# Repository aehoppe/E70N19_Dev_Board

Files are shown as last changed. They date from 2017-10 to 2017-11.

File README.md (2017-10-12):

# E70N19_Dev_Board
 Repository for developing an ATSAME70N19-based dev board for Eclectronics FA 2017

## Brief Description of Board Design

Currently the board is designed to fit onto a 10cm X 10cm PCB. We will be using female header pins, much like an Arduino, on opposite edges of the PCB. 

## Changes to Schematic & BOM

There were no changes to the BOM.

The schematic had a few modifications based on feedback we received.

- Adding a voltage divider to TPS2112A to prevent brown out
- Added load capacitors to our RTC crystal
- Added a 10uF to BM71
- Added power LED to show status of power
- Changed nRST button to drive it to ground instead of power
- Added 30Ohm resistors to USB data lines
- Added connections to ground, 3v3 and VBUS to connectors

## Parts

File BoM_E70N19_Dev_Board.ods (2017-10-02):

Reference | Value | Datasheet | Tolerance | Digikey | Price | In Stock
C1 | 4.7uF | https://www.digikey.com/product-detail/en/samsung-electro-mechanics-america-inc/CL10B475KQ8NQNC/1276-2087-1-ND/3890172 |  | 1276-2087-1-ND | $0.10 | No
C3 | 4.7uF |  |  |  | $0.10 | No
C6 | 4.7uF |  |  |  | $0.10 | No
C23 | 18pF | https://www.digikey.com/product-detail/en/murata-electronics-north-america/GRM1555C1H180JA01D/490-5858-1-ND/2854384 |  | 490-5858-1-ND | $0.10 | No
C24 | 18pF |  |  |  | $0.10 | No
C10 | 100nF |  |  |  |  | Yes
C11 | 100nF |  |  |  |  | Yes
C12 | 100nF |  |  |  |  | Yes
C13 | 100nF |  |  |  |  | Yes
C14 | 1uF |  |  |  |  | Yes
C15 | 100nF |  |  |  |  | Yes
C16 | 100nF |  |  |  |  | Yes
C17 | 100nF |  |  |  |  | Yes
C18 | 100nF |  |  |  |  | Yes
C19 | 100nF |  |  |  |  | Yes
C2 | 10uF |  |  |  |  | Yes
C20 | 100nF |  |  |  |  | Yes
C21 | 100nF |  |  |  |  | Yes
C22 | 10pF |  |  |  |  | Yes
C25 | 1uF |  |  |  |  | Yes
C26 | 100nF |  |  |  |  | Yes
C27 | 100nF |  |  |  |  | Yes
C28 | 100nF |  |  |  |  | Yes
C4 | 0.1uF |  |  |  |  | Yes
C5 | 10uF |  |  |  |  | Yes
C7 | 100nF |  |  |  |  | Yes
C8 | 100nF |  |  |  |  | Yes
C9 | 100nF |  |  |  |  | Yes
R1 | 475 |  |  |  |  | Yes
R10 | 100K |  |  |  |  | Yes
R11 | 100K |  |  |  |  | Yes
R2 | 402 |  |  |  |  | Yes
R3 | 2K |  |  |  |  | Yes
R4 | 4.99K |  |  |  |  | Yes
R12 | 63.4 |  |  |  |  | Yes
R5 | 4.75K |  |  |  |  | Yes
R6 | 0 | https://www.digikey.com/product-detail/en/yageo/RC0603JR-070RL/311-0.0GRCT-ND/729622 |  | 311-0.0GRCT-ND | $0.10 | No
R7 | -1 (0 but DNP) |  |  |  |  | No
R8 | 402 |  |  |  |  | Yes
R9 | 100K |  |  |  |  | Yes
D1 | LED |  |  |  |  | Yes
D2 | LED |  |  |  |  | Yes
FP1 | BM71BLES1FC2 | https://www.digikey.com/product-detail/en/microchip-technology/BM71BLES1FC2-0002AA/BM71BLES1FC2-0002AA-ND/5886086 | N/A | BM71BLES1FC2-0002AA-ND | $7.38 | No
J1 | USB_OTG |  |  |  |  | Yes
J2 | Battery | https://www.digikey.com/product-detail/en/jst-sales-america-inc/S2B-PH-SM4-TB-LF-SN/455-1749-1-ND/926846 |  | 455-1749-1-ND | $0.58 | No
J3 | JTAGSEL_JUMPER 1x3 |  |  |  |  | Yes
J5 | ERASE_JUMPER 1x3 |  |  |  |  | Yes
J4 | UART_PROG 1x2 |  |  |  |  | Yes
J7 | CAN 1x2 |  |  |  |  | Yes
J6 | ARM-Cortex-Debug-10 | https://www.digikey.com/product-detail/en/samtec-inc/FTSH-105-01-F-DV-K/SAM8796-ND/2649974 |  | SAM8796-ND | $2.90 | No
J8 | Conn_02x15_Counter_Clockwise | https://www.digikey.com/product-detail/en/sullins-connector-solutions/PPTC152LFBN-RC/S7083-ND/810221 |  | S7083-ND | $2.74 | No
J9 | Conn_02x15_Counter_Clockwise |  |  |  | $2.74 | No
L1 | 470R @ 100MHz |  |  | 445-5218-1-ND | $0.10 | No
L2 | 470R @ 100MHz |  |  |  | $0.10 | No
SW1 | NRST_BUTTON |  |  |  |  | Yes
U1 | MCP73831 | http://ww1.microchip.com/downloads/en/DeviceDoc/20001984g.pdf |  | MCP73831T-2ACI/OTCT-ND | $0.59 | No
U2 | TPS2112A | http://www.ti.com/lit/ds/symlink/tps2112a.pdf |  | 296-16938-1-ND | $2.46 | No
U3 | SPX3819M5-L-3-3 | https://www.digikey.com/product-detail/en/exar-corporation/SPX3819M5-L-3-3-TR/1016-1873-1-ND/3586590 |  | 1016-1873-1-ND | $0.72 | No
U4 | ATSAME70N19 |  |  | ATSAME70N19A-AN-ND | $9.38 | No
U5 | RT9818A-18GV |  |  | RT9818A-18GV-ND | $0.40 | No | <- Out of stock, Substitute: 1028-1020-1-ND
U6 | SN65HVD233-Q1 | https://www.digikey.com/product-detail/en/texas-instruments/SN65HVD233DR/296-35967-1-ND/4134960 |  | 296-35967-1-ND | $2.75 | No
Y1 | Crystal_GND23_Small | https://www.digikey.com/products/en?keywords=%20535-10240-1-ND%20 |  | 535-10240-1-ND | $0.40 | No
Y2 | Crystal | https://support.epson.biz/td/api/doc_check.php?dl=brief_FA-238V_en.pdf |  | SER3686CT-ND | $0.43 | No
 | Jumper 1x2 | https://www.digikey.com/product-detail/en/sullins-connector-solutions/SPC02SYAN/S9001-ND/76375 |  | S9001-ND | $0.13 | No
 | Jumper 1x2 |  |  |  | $0.13 | No
 |  |  |  |  | $34.40

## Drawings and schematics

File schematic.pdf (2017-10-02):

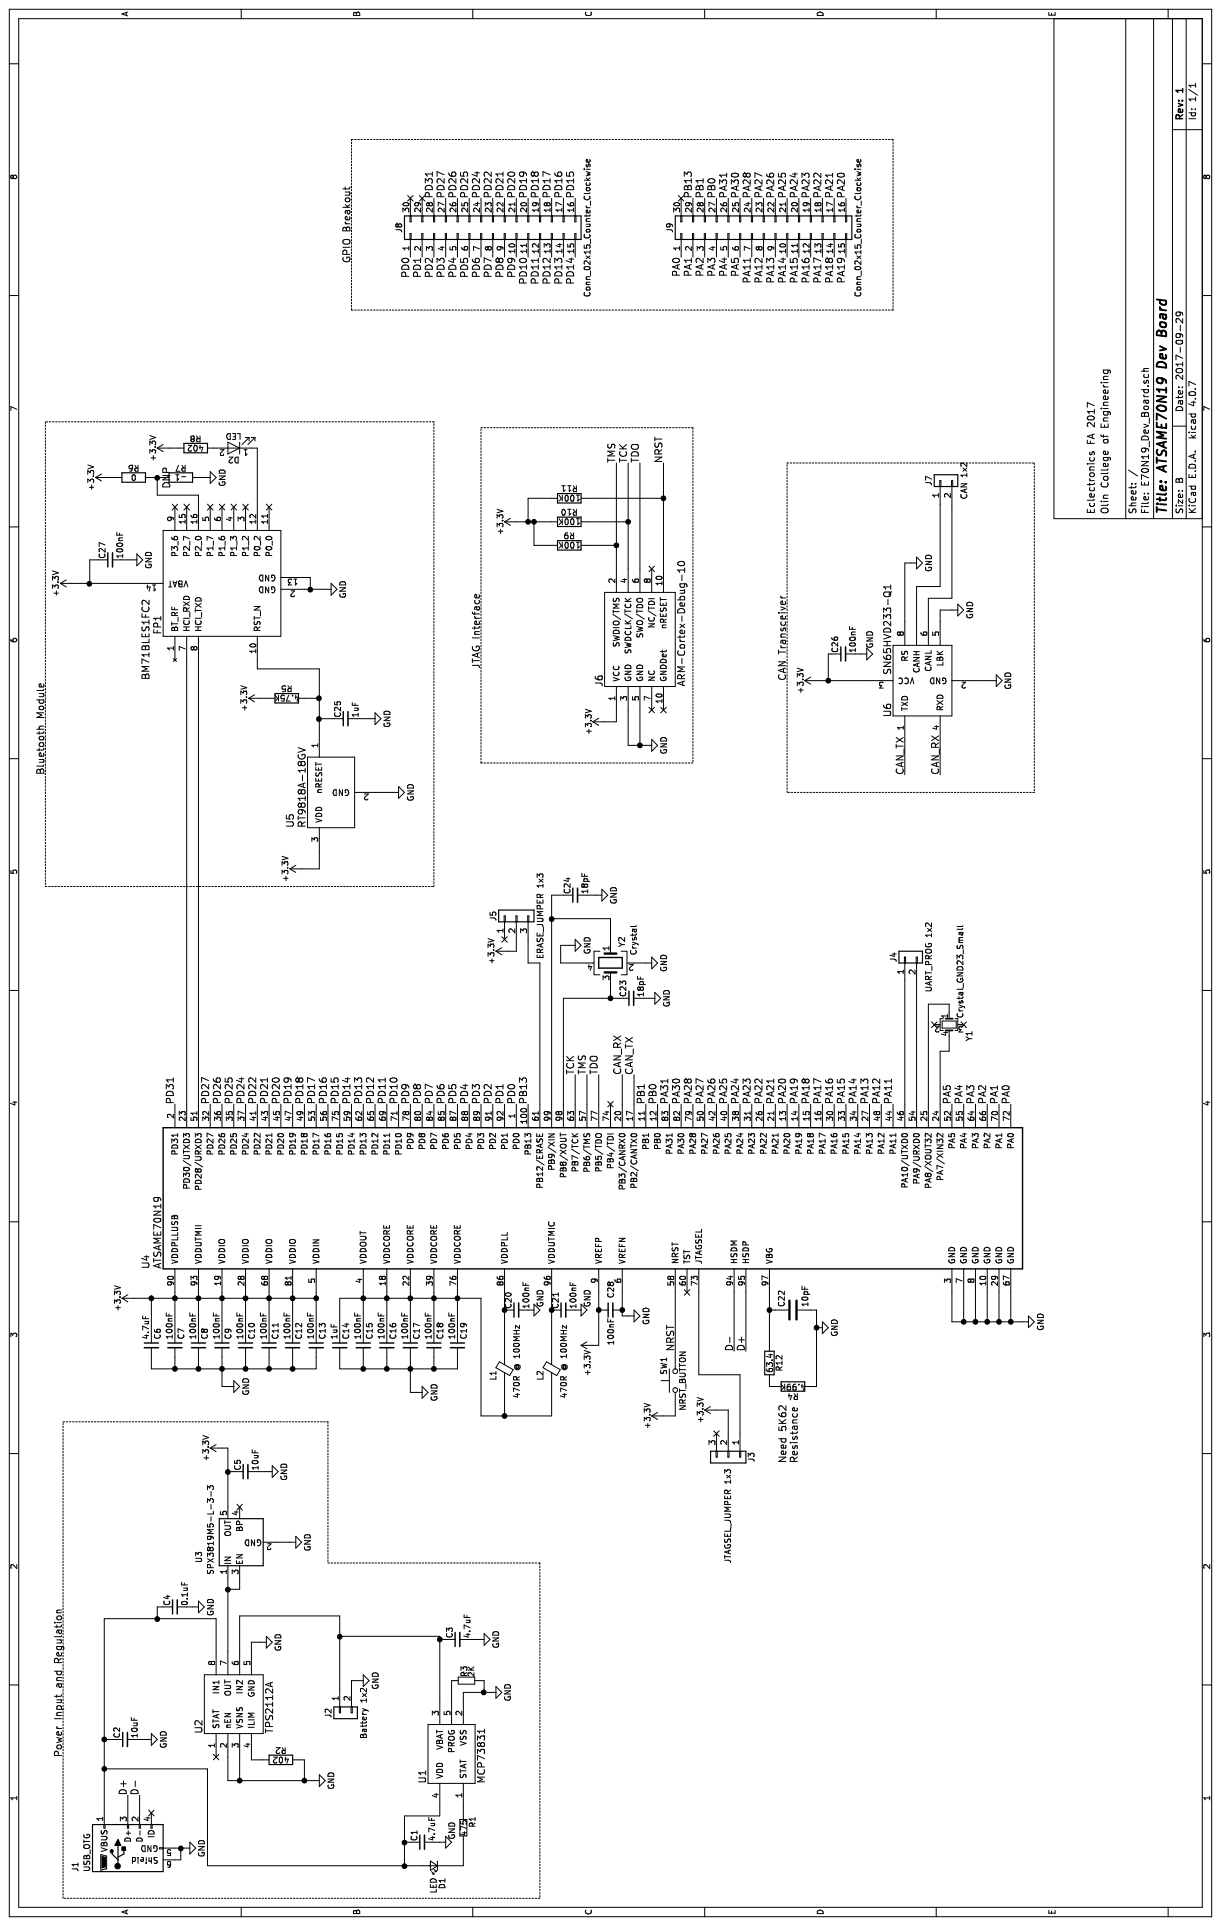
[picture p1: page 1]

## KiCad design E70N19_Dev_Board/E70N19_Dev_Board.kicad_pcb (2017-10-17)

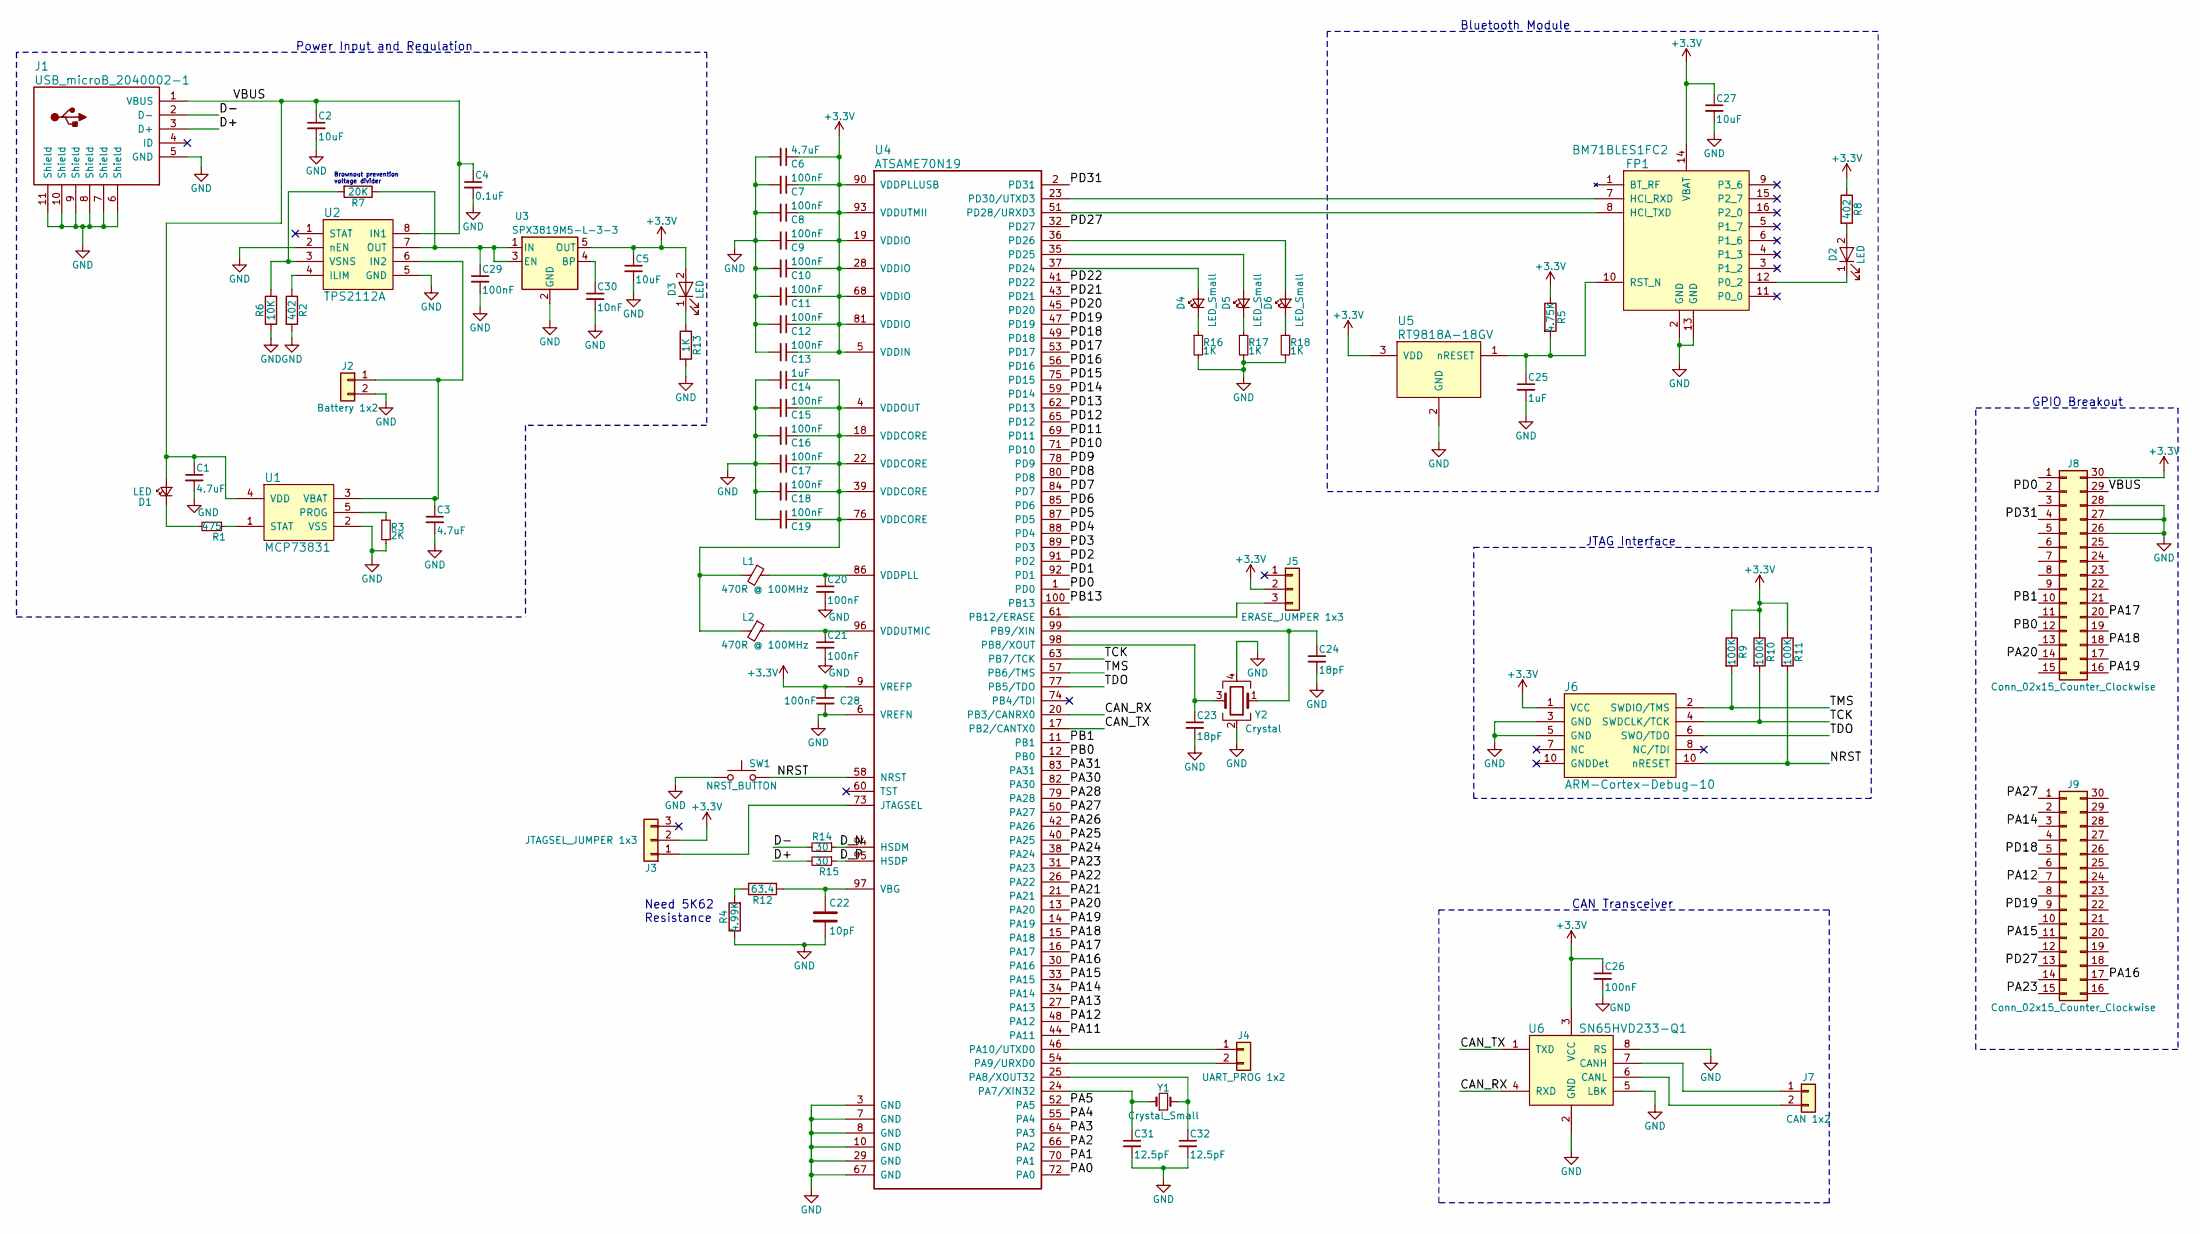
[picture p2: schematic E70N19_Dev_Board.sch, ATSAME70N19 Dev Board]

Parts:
C1, C3, C6: 4.7uF; C_0603
C2, C5, C27: 10uF; C_0805
C4: 0.1uF; C_0603
C7, C8, C9, C10, C11, C12, C13, C15, C16, C17, C18, C19, C20, C21, C26, C28, C29: 100nF; C_0603
C14, C25: 1uF; C_0603
C22: 10pF; C_0603
C23, C24: 18pF; C_0603
C30: 10nF; C_0603
C31, C32: 12.5pF; C_0603
D1, D2, D3: LED; LED_0805
D4, D5, D6: LED_Small; LED_0805
FP1: BM71BLES1FC2
J1: USB_microB_2040002-1
J2: Battery 1x2; JST_PH_S2B-PH-SM4-TB_02x2.00mm_Angled
J3: JTAGSEL_JUMPER 1x3; Pin_Header_Straight_1x03_Pitch2.54mm
J4: UART_PROG 1x2; Pin_Header_Straight_1x02_Pitch2.54mm
J5: ERASE_JUMPER 1x3; Pin_Header_Straight_1x03_Pitch2.54mm
J6: ARM-Cortex-Debug-10; Pin_Header_Straight_2x05_Pitch2.54mm
J7: CAN 1x2; Pin_Header_Straight_1x02_Pitch2.54mm
J8, J9: Conn_02x15_Counter_Clockwise; Pin_Header_Straight_2x15_Pitch2.54mm
L1, L2: 470R @ 100MHz; R_0603; Digikey 445-5218-1-ND
R1: 475; R_0603
R2, R8: 402; R_0603
R3: 2K; R_0603
R4: 4.99K; R_0603
R5: 4.75K; R_0603
R6: 10K; R_0603
R7: 20K; R_0603
R9, R10, R11: 100K; R_0603
R12: 63.4; R_0603
R13, R16, R17, R18: 1K; R_0603
R14, R15: 30; R_0603
SW1: NRST_BUTTON; PTS820_J15M_SMTR_LFS
U1: MCP73831; SOT-23-5
U2: TPS2112A; TSSOP-8_4.4x3mm_Pitch0.65mm
U3: SPX3819M5-L-3-3; SOT-23-5
U4: ATSAME70N19; LQFP-100_14x14mm_Pitch0.5mm
U5: RT9818A-18GV; SOT-23
U6: SN65HVD233-Q1; SOIC-8_3.9x4.9mm_Pitch1.27mm
Y1: Crystal_Small; ECS-.327-12.5-34B-TR
Y2: Crystal; Crystal_SMD_SeikoEpson_FA238-4pin_3.2x2.5mm

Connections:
+3V3: C5.1, C6.1, C7.1, C8.1, C9.1, C10.1, C11.1, C12.1, C13.1, C26.1, C27.1, C28.1, D3.2 (A), FP1.14 (VBAT), J3.2, J5.2, J6.1 (VCC), J8.30, R5.1, R8.1, R9.1, R10.1, R11.1, U3.5 (OUT), U4.5 (VDDIN), U4.9 (VREFP), U4.19 (VDDIO), U4.28 (VDDIO), U4.68 (VDDIO), U4.81 (VDDIO), U4.90 (VDDPLLUSB), U4.93 (VDDUTMII), U5.3 (VDD), U6.3 (VCC)
/CAN_RX: U4.20 (PB3/CANRX0), U6.4 (RXD)
/CAN_TX: U4.17 (PB2/CANTX0), U6.1 (TXD)
/D+: J1.3 (D+), R15.2
/D-: J1.2 (D-), R14.2
/D_N: R14.1, U4.94 (HSDM)
/D_P: R15.1, U4.95 (HSDP)
/NRST: J6.10 (GNDDet), R11.2, SW1.2, U4.58 (NRST)
/PA0: U4.72 (PA0)
/PA1: U4.70 (PA1)
/PA2: U4.66 (PA2)
/PA3: U4.64 (PA3)
/PA4: U4.55 (PA4)
/PA5: U4.52 (PA5)
/PA11: U4.44 (PA11)
/PA12: J9.7, U4.48 (PA12)
/PA13: U4.27 (PA13)
/PA14: J9.3, U4.34 (PA14)
/PA15: J9.11, U4.33 (PA15)
/PA16: J9.17, U4.30 (PA16)
/PA17: J8.20, U4.16 (PA17)
/PA18: J8.18, U4.15 (PA18)
/PA19: J8.16, U4.14 (PA19)
/PA20: J8.14, U4.13 (PA20)
/PA21: U4.21 (PA21)
/PA22: U4.26 (PA22)
/PA23: J9.15, U4.31 (PA23)
/PA24: U4.38 (PA24)
/PA25: U4.40 (PA25)
/PA26: U4.42 (PA26)
/PA27: J9.1, U4.50 (PA27)
/PA28: U4.79 (PA28)
/PA30: U4.82 (PA30)
/PA31: U4.83 (PA31)
/PB0: J8.12, U4.12 (PB0)
/PB1: J8.10, U4.11 (PB1)
/PB13: U4.100 (PB13)
/PD0: J8.2, U4.1 (PD0)
/PD1: U4.92 (PD1)
/PD2: U4.91 (PD2)
/PD3: U4.89 (PD3)
/PD4: U4.88 (PD4)
/PD5: U4.87 (PD5)
/PD6: U4.85 (PD6)
/PD7: U4.84 (PD7)
/PD8: U4.80 (PD8)
/PD9: U4.78 (PD9)
/PD10: U4.71 (PD10)
/PD11: U4.69 (PD11)
/PD12: U4.65 (PD12)
/PD13: U4.62 (PD13)
/PD14: U4.59 (PD14)
/PD15: U4.75 (PD15)
/PD16: U4.56 (PD16)
/PD17: U4.53 (PD17)
/PD18: J9.5, U4.49 (PD18)
/PD19: J9.9, U4.47 (PD19)
/PD20: U4.45 (PD20)
/PD21: U4.43 (PD21)
/PD22: U4.41 (PD22)
/PD27: J9.13, U4.32 (PD27)
/PD31: J8.4, U4.2 (PD31)
/TCK: J6.4 (SWDCLK/TCK), R10.2, U4.63 (PB7/TCK)
/TDO: J6.6 (SWO/TDO), U4.77 (PB5/TDO)
/TMS: J6.2 (SWDIO/TMS), R9.2, U4.57 (PB6/TMS)
/VBUS: C1.1, C2.1, C4.1, D1.2 (A), J1.1 (VBUS), J8.29, U1.4 (VDD), U2.8 (IN1)
GND: C1.2, C2.2, C3.2, C4.2, C5.2, C6.2, C7.2, C8.2, C9.2, C10.2, C11.2, C12.2, C13.2, C14.2, C15.2, C16.2, C17.2, C18.2, C19.2, C20.2, C21.2, C22.2, C23.2, C24.2, C25.2, C26.2, C27.2, C28.2, C29.2, C30.2, C31.2, C32.2, FP1.2 (GND), FP1.13 (GND), J1.5 (GND), J1.6 (Shield), J1.7 (Shield), J1.8 (Shield), J1.9 (Shield), J1.10 (Shield), J1.11 (Shield), J2.2, J6.3 (GND), J6.5 (GND), J8.26, J8.27, J8.28, R2.2, R3.2, R4.1, R6.1, R13.2, R16.2, R17.2, R18.2, SW1.1, U1.2 (VSS), U2.2 (nEN), U2.5 (GND), U3.2 (GND), U4.3 (GND), U4.6 (VREFN), U4.7 (GND), U4.8 (GND), U4.10 (GND), U4.29 (GND), U4.67 (GND), U5.2 (GND), U6.2 (GND), U6.5 (LBK), U6.8 (RS), Y2.2, Y2.4
unnamed: C3.1, J2.1, U1.3 (VBAT), U2.6 (IN2)
unnamed: C14.1, C15.1, C16.1, C17.1, C18.1, C19.1, L1.2, L2.2, U4.4 (VDDOUT), U4.18 (VDDCORE), U4.22 (VDDCORE), U4.39 (VDDCORE), U4.76 (VDDCORE)
unnamed: C20.1, L1.1, U4.86 (VDDPLL)
unnamed: C21.1, L2.1, U4.96 (VDDUTMIC)
unnamed: C22.1, R12.1, U4.97 (VBG)
unnamed: C23.1, U4.98 (PB8/XOUT), Y2.3
unnamed: C24.1, U4.99 (PB9/XIN), Y2.1
unnamed: C25.1, FP1.10 (RST_N), R5.2, U5.1 (nRESET)
unnamed: C29.1, R7.1, U2.7 (OUT), U3.1 (IN), U3.3 (EN)
unnamed: C30.1, U3.4 (BP)
unnamed: C31.1, U4.24 (PA7/XIN32), Y1.1
unnamed: C32.1, U4.25 (PA8/XOUT32), Y1.2
unnamed: D1.1 (K), R1.2
unnamed: D2.1 (K), FP1.12 (P0_2)
unnamed: D2.2 (A), R8.2
unnamed: D3.1 (K), R13.1
unnamed: D4.1 (K), R16.1
unnamed: D4.2 (A), U4.37 (PD24)
unnamed: D5.1 (K), R17.1
unnamed: D5.2 (A), U4.35 (PD25)
unnamed: D6.1 (K), R18.1
unnamed: D6.2 (A), U4.36 (PD26)
unnamed: FP1.7 (HCI_RXD), U4.23 (PD30/UTXD3)
unnamed: FP1.8 (HCI_TXD), U4.51 (PD28/URXD3)
unnamed: J3.1, U4.73 (JTAGSEL)
unnamed: J4.1, U4.46 (PA10/UTXD0)
unnamed: J4.2, U4.54 (PA9/URXD0)
unnamed: J5.3, U4.61 (PB12/ERASE)
unnamed: J7.1, U6.7 (CANH)
unnamed: J7.2, U6.6 (CANL)
unnamed: R1.1, U1.1 (STAT)
unnamed: R2.1, U2.4 (ILIM)
unnamed: R3.1, U1.5 (PROG)
unnamed: R6.2, R7.2, U2.3 (VSNS)
unnamed: R4.2, R12.2

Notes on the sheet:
Power Input and Regulation
GPIO Breakout
CAN Transceiver
JTAG Interface
Bluetooth Module
Need 5K62 Resistance
Brownout prevention voltage divider

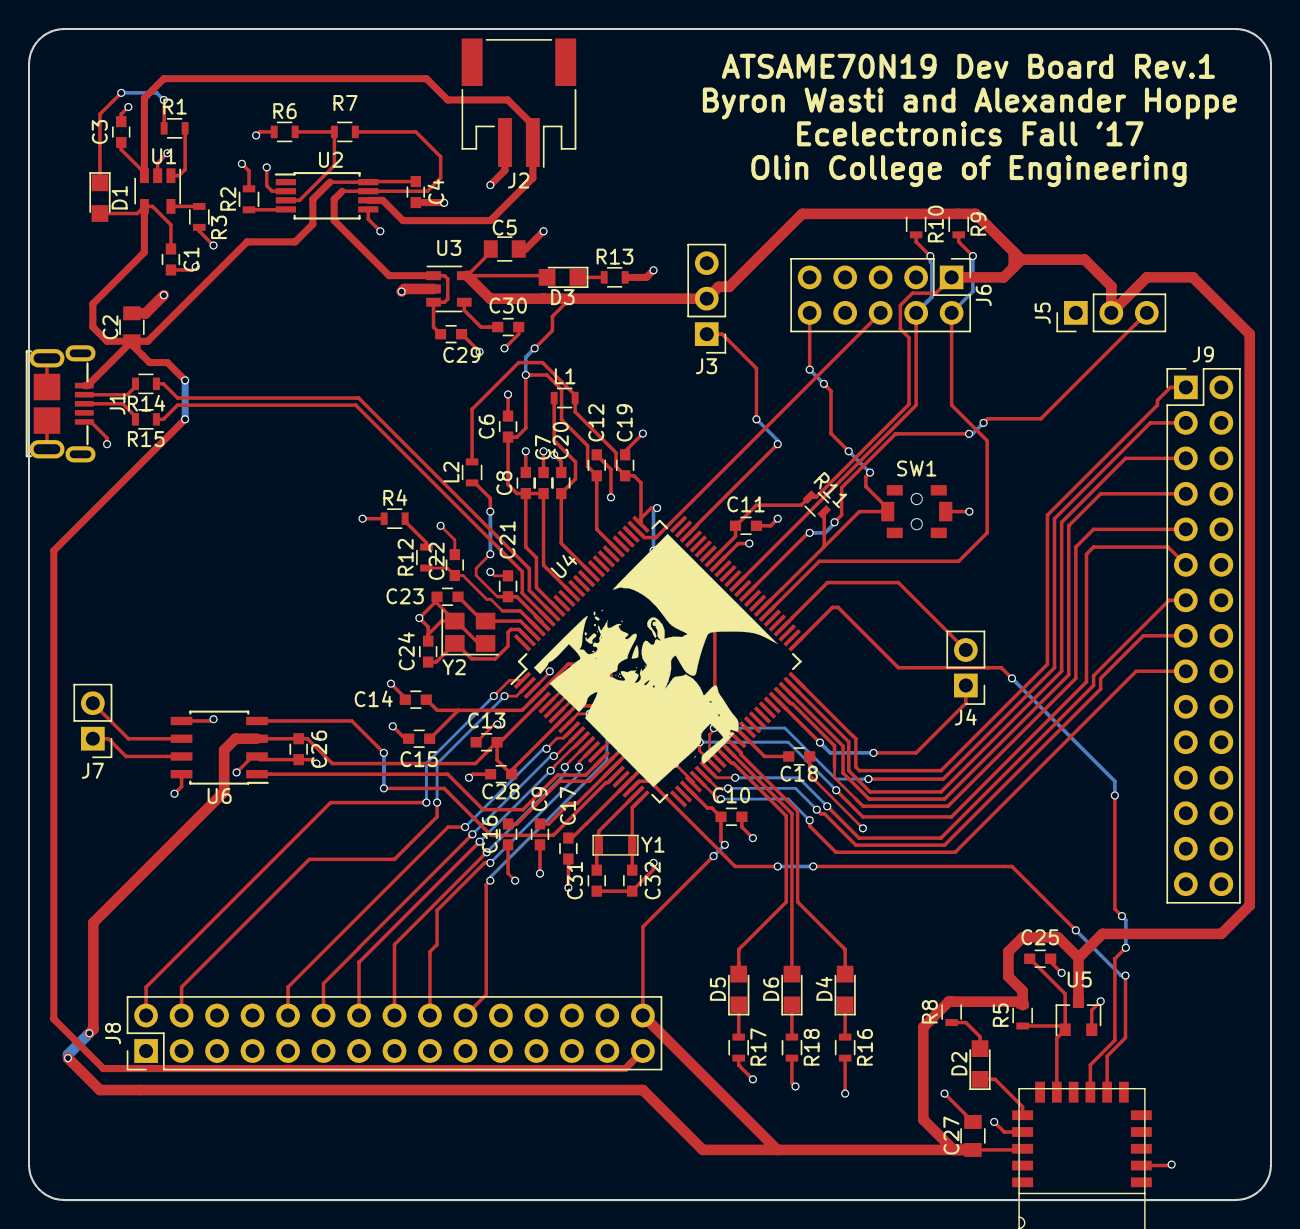
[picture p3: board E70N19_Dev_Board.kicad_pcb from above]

Board: 2 copper layers, 88.9 x 83.8 mm, 77 parts (0 on the bottom side), 65 nets.

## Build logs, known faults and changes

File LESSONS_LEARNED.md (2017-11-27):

---
geometry: margin=1cm
---
# Lessons Learned

This project was a mixed bag for validating subsystems for our final project design. We had little success with our MCU and BLE module, but we were able to prove out our power management and LCD screen.

## Microcontroller

For this project we chose the ATSAME70N19 Arm Cortex-M7 microcontroller, with the hopes that it would be easy to work with and give us a lot of power and flexibility. We were familiar with Atmel ATmega 8-bit microcontrollers, and we thought this would give us an advantage moving up to 32-bit ARM core Atmel devices. We also selected this device for its purported ease of programming due to its USB-capable default bootloader. However, despite doing a bit of research before-hand about how to program the chip, we were unaware that the ATSAM series is actually known for having pretty awful software support.

We found this out when we got our board back and tried to actually program it. The bootloader that the chip comes with allowed for us to connect to the device, but when we tried to upload code nothing happened. We had a compiling firmware image, but we weren't able to get the device to respond in a predictable way. It was also difficult to find any documentation on memory mapping to debut that issue, nor could we find much top-leve documentation on how to do anything at all. We probably wouldn't have figured out how to get any code compiling without the help of the Atmel-START webapp that provided us with a massive directory of boilerplate code and drivers. We were able to build a main function that compiled, but we were defeated trying to debug the uploading process.

After spending some time trying to get anything working, we decided to abandon the efforts and focus on selecting another MCU. Using the lessons we learned from struggling with obstruse ATSAM documentation, we chose a manufacturer who is known for great programming support (STM) and which has a lot of firmware documentation. We made sure to pick a specific model with a lot of community support as well.

## BLE Module

Unfortunately we ran into similar issues with the BM71 bluetooth module as with our ATSAM microcontroller: we implemented the hardware correctly, but we were unable to program/use it. By default, the BM71 is configured to communicate with other BM71s using a proprietary protocol. In order to change this, you have to use a proprietary Windows program to modify device configuration. However, we hadn't foreseen this difficulty, and didn't design our hardware to allow the module to be connected to a computer separately.

We ended up deciding to spec an alternative BLE module which happened to have the exact same castellated footprint (and is probably the same chip with different firmware). This new module, however, has an open configuration spec, which will allow us to configure it using our MCU.

This is another instance of us learning how important it is to research *everything we need to use* (especially how to program it) for a component before deciding on something.

## Power Circuitry

The main saving grace of this board was that we did get the power-multiplexing circuitry worked out. There were a few issues at first, such as the 3.3V line being a saw-tooth 1.8V signal, but we traced it back to a simple schematic error and resolved it with rework. In the end, we were able to have a fully functional 5V to 3.3V regulator, a multiplexer that switched between USB and LiPoly battery, as well as an independent battery charger. This system wasn't particularly complicated or risky, but we succeeded in proving out a reusable subsystem for future designs.

## Testing our Project 3 LCD Screen

The last use we found for our board is using it to test our LCD screen for our 3rd project. The pitch for our LCD screen connector was 0.5mm, and the pitch for our MCU was also 0.5mm, so it was possible to put our connector on the footprint of the MCU. It was also lucky that our connector had 10 pins which needed to be different, and there was exactly 1 place where the MCU footprint had 10 pins that were contiguous, different, and routed to other parts of the board where we could connect a wire to them.

Thus, we were able to connect our LCD screen to an Arduino using our board and some trickery, and test the functionality. Although we did not get a perfect image displayed, we did find a lot of example code for working with our specific line of Sharp LCD screens, and we were able to display some scrambled lines adn pixels. We believe the reason we did not get a nice image is that we did not toggle the EXTCOMIN pin at a minimum of 1Hz which prevents charge buildup on the LCD screen. However, we did get enough information to convince ourselves that we could work with the screen for our final project.

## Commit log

2017-09-28 Library and Schematic development
    [E70N19_Dev_Board.kicad_pcb, E70N19_Dev_Board.sch, _saved_E70N19_Dev_Board.sch]
2017-09-28 added/edited bluetooth module
    [_saved_E70N19_Dev_Board.sch]
2017-09-28 Fixing up library
    [E70N19_Dev_Board.kicad_pcb]
2017-09-28 Merged ATSAME70N19 library
    [E70N19_Dev_Board.sch]
2017-09-29 Begun power connections on ATSAME70N19
    [E70N19_Dev_Board.sch]
2017-10-01 Implements power schematic
    [E70N19_Dev_Board.sch]
2017-10-02 Finished Schematic
    [E70N19_Dev_Board.sch]
2017-10-02 Updating schematic with corrected values
    [E70N19_Dev_Board.sch]
2017-10-02 Finishing BoM and other requirements
    [BoM_E70N19_Dev_Board.ods, E70N19_Dev_Board.sch]
2017-10-02 Adds PDF schematic
2017-10-06 Fixing up schematic based on design review notes
    [E70N19_Dev_Board.sch]
2017-10-07 Began associating footprints
    [_saved_E70N19_Dev_Board.sch]
2017-10-07 Hoppe did not save correctly
    [E70N19_Dev_Board.sch, _saved_E70N19_Dev_Board.sch]
2017-10-07 Fixing schematic error
    [E70N19_Dev_Board.sch]
2017-10-07 Brad's micro OTG connector
    [E70N19_Dev_Board.sch]
2017-10-07 More footprints
    [E70N19_Dev_Board.sch]
2017-10-07 Fixing footprint for BLE module
2017-10-08 Added tactile switch footprint
2017-10-08 Finishing PCB component placement
    [E70N19_Dev_Board.kicad_pcb, E70N19_Dev_Board.sch]
2017-10-08 Added debug LEDs
    [E70N19_Dev_Board.kicad_pcb, E70N19_Dev_Board.sch]
2017-10-11 Initial routing
    [E70N19_Dev_Board.kicad_pcb, E70N19_Dev_Board.sch]
2017-10-12 Beginning to route
    [E70N19_Dev_Board.kicad_pcb]
2017-10-12 Edited schematic to make pin fanout easier
    [E70N19_Dev_Board.sch]
2017-10-12 More excape routing
    [E70N19_Dev_Board.kicad_pcb]
2017-10-12 Updated with new schematic
    [E70N19_Dev_Board.kicad_pcb]
2017-10-12 Finishing double layer board
    [E70N19_Dev_Board.kicad_pcb, E70N19_Dev_Board.sch]
2017-10-12 finishing touches
    [E70N19_Dev_Board.kicad_pcb]
2017-10-12 Adding Hoppe's face
    [E70N19_Dev_Board.kicad_pcb]
2017-10-12 Revert "finishing touches"
    This reverts commit 4a8290c698ae611552ebb1913fe9187be52cce0b.
    [E70N19_Dev_Board.kicad_pcb]
2017-10-16 Fixing unconnected ground nets
    [E70N19_Dev_Board.kicad_pcb]
2017-10-17 Fixing missing uC footprint
    [E70N19_Dev_Board.kicad_pcb]
2017-10-17 No rat lines
    [E70N19_Dev_Board.kicad_pcb]
2017-10-26 Edited schematic to reflect PMUX rework
    [E70N19_Dev_Board.sch]
2017-11-27 Fix library issues
    [E70N19_Dev_Board.sch]
